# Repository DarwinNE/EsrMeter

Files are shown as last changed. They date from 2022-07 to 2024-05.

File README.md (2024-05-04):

# EsrMeter
An open hardware in-circuit ESR meter for electrolytic capacitors.

This circuit is based on a PIC16F883 that controls a simple lock-in circuit to measure in circuit the ESR and in some cases the capacitance of electrolytic capacitors.

The circuit has been designed by Davide Bucci, the PCB by Etenmenanki using Eagle. The size of the PCBs is compatible with the free version of the program.

A description (in italian language) of the circuit can be found here: https://www.electroyou.it/darwinne/wiki/misurare-esr-di-condensatori-con-circuito-lock-in

Two versions of the PCB exist. The first one has the digital and analog parts split in two. This approach has the advantage that one can test the analog board with something different from the PIC16F883 (i.e. a STM32 or an Arduino board, for instance). The version with the two boards separated requires some corrections, look at the associated files if you try to build them.
The second version has all digital and analog circuits on the same board and it is much more compact. I ordered the PCB on July 24, 2022, I received them and assembled a first prototype at the end of August 2022. It worked at the first attempt, but there is a shift in low ESR values and moderate to large capacitance (>300µF) that I am currently (mid Sept 2022) investigating.

All components are SMD. In the "all in one" boards, two different versions of the PIC16F883 can be used to cope with the pandemic scarcity of components: SOIC and SSOP. I think the PIC16F886 can be used at the place of the PIC16F883 with minimal changes.

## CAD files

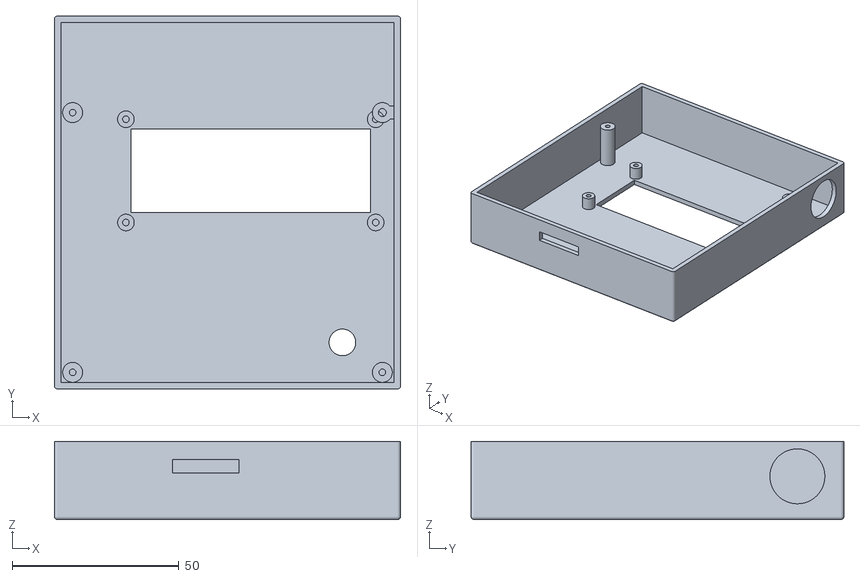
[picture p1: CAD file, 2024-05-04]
3D_printed_box/box.stl
104.0 x 112.0 x 23.5

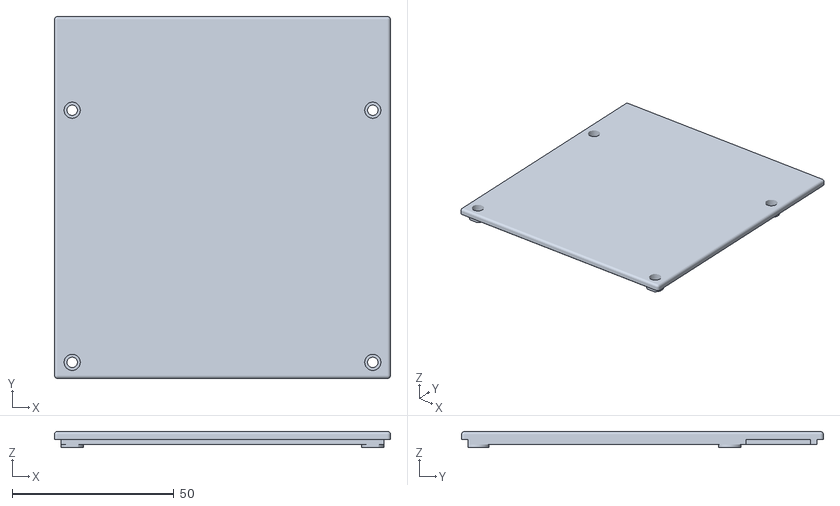
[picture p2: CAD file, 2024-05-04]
3D_printed_box/lid.stl
104.0 x 112.0 x 5.00

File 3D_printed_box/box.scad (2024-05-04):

x_distance_screw=93;
y_distance_screw=78+0;

x_sh=-46.5;
y_sh=-45-6;

x_lcd_pos=-3.5;
y_lcd_pos=-5;

x_lcd_size=72;
y_lcd_size=25;


x_lcd_peg_pos= 2.5; // Position (with respect to the top left aperture of the screen)
y_lcd_peg_pos= 3; // Position (with respect to the top left aperture of the screen)

width_lcd_pegs = 75; // Horizontal distance between screws for the LCD module
height_lcd_pegs= 31; // Vertical distance between screws

x_knob_pos=-12;
y_knob_pos=-69;

x_slot_pos=-55+2;
y_slot_pos=-85;

x_switch_pos=-100+12+8;
y_switch_pos=-69;


x_switch_pos_l=2;
y_switch_pos_l=15;

hole_diam_screw_PCB = 1;
hole_diam_screw_LCD = 1;



internal_height=26;

//top();
translate ([0,0,20]) bottom();

module bottom() { 
    difference() {
        union() {
            difference() {
                union () {
                    difference() {
                        rounded_cube(100+4, 108+4,4);
                        translate([0,0,-2]) cube([110,120,3], center=true);
                    }
                    translate([0,0,-1]) cube([100,108,2], center=true);  
                }
                translate([0,0,-1.5]) cube([98,106,3], center=true);  
            }
            translate([0,0,-3]) {
                translate([x_sh,y_sh,0]) bottom_peg();
                translate([x_sh,y_sh+y_distance_screw,0]) bottom_peg();
                translate([x_sh+x_distance_screw,y_sh,0]) bottom_peg();
                translate([x_sh+x_distance_screw,y_sh+y_distance_screw,0])
                    bottom_peg();
            }
        }
    
        translate([0,0,-2]) {
            translate([x_sh,y_sh,0]) screw_hole();
            translate([x_sh,y_sh+y_distance_screw,0]) screw_hole();
            translate([x_sh+x_distance_screw,y_sh,0]) screw_hole();
            translate([x_sh+x_distance_screw,y_sh+y_distance_screw,0]) screw_hole();
        }
        translate([50,42,-3]) cube([20,20,5], center=true);
        translate([0,-56.5,-4.5]) cube([110,5,8], center=true);
    }
}

module screw_hole()
{
    cylinder(r=2.5,h=6);
}

module bottom_peg()
{
    difference() {
        cylinder(r=3.5,h=4);
        translate([0,0,-2]) cylinder(r=1.6,h=6);
    }
}


module top() {

    difference() {
        union () {
            rounded_cube(100+4, 108+4,internal_height);
        }
        translate([0,0,2]) cube([100,108,internal_height], center=true);    
        translate([0,0,26/2]) cube([100+5,108+5,5], center=true);
        
        // aperture for the LCD, calculated from the left-top screw.
        translate([x_sh+x_distance_screw+x_lcd_pos-x_lcd_size/2,
            y_sh+y_distance_screw+y_lcd_pos-y_lcd_size/2,
            -26/2])
        {    
            cube([x_lcd_size,y_lcd_size,5], center=true);
        }
        
        // Hole for the encoder knob
        translate([x_sh+x_distance_screw+x_knob_pos,
            y_sh+y_distance_screw+y_knob_pos,
            -26/2-2])
        {    
            cylinder(r=4,h=18);
        }
        // Hole for the wires
        translate([x_sh+x_distance_screw+x_slot_pos,
            y_sh+y_distance_screw+y_slot_pos,
            5-2])
        {    
            cube([20,10,4], center=true);
        }
        // Hole for the power switch (top switch)
        /*translate([x_sh+x_distance_screw+x_switch_pos,
            y_sh+y_distance_screw+y_switch_pos,
            -26/2-2])
        {    
            cylinder(r=4,h=18);
        }*/
        
        // Hole for the power switch (lateral switch)
        translate([x_sh+x_distance_screw+x_switch_pos_l,
            y_sh+y_distance_screw+y_switch_pos_l,
            0])
        {    
            rotate([0,90,0]) cylinder(r=16.5/2,h=18);
        }
    }
    // Main PCB and backside screws
    translate([0,0,internal_height-17-internal_height/2+1]) {
        translate([x_sh,y_sh,-17/2]) peg();
        translate([x_sh,y_sh+y_distance_screw,-17/2]) peg();
        translate([x_sh+x_distance_screw,y_sh,-17/2]) peg();
        // This screw is covered by the LCD
        translate([x_sh+x_distance_screw,y_sh+y_distance_screw,-17/2+10])  {
            difference() {
                union() {
                    translate([2,0,3]) {
                        cube([5,4,7],center=true);
                    }
                    cylinder(r=3,h=7);
                }
                translate([0,0,-2]) cylinder(r=1.2,h=10);
            }
        }
    }

    // LCD support screws
    translate([x_sh+x_distance_screw+x_lcd_pos+x_lcd_peg_pos,
            y_sh+y_distance_screw+y_lcd_pos+y_lcd_peg_pos,
            -26/2+2]) {
        small_peg();
        translate([0,-height_lcd_pegs,0]) small_peg();
        translate([-width_lcd_pegs,0,0]) small_peg();
        translate([-width_lcd_pegs,-height_lcd_pegs,0]) small_peg();

    }

}

module peg()
{
    difference() {
        cylinder(r=3,h=17);
        translate([0,0,5]) cylinder(r=hole_diam_screw_PCB,h=13);
    }
}

module small_peg()
{
    difference() {
        cylinder(r=2.5,h=5);
        translate([0,0,0]) cylinder(r=hole_diam_screw_LCD,h=6);
    }
}

/*translate([7,-10,-13.5]) mirror()
        linear_extrude(1)
            #text("Cap tester", size=10, halign = "center", valign="center");  
*/



$fn=64;

module rounded_cube(esizex, esizey,esizez,radius=1)
{
    hull() {
        sizex=esizex-radius*2;
        sizey=esizey-radius*2;
        sizez=esizez-radius*2;
         
        
        translate([sizex/2,sizey/2,sizez/2]) sphere(r=radius);
        translate([-sizex/2,sizey/2,sizez/2]) sphere(r=radius);
        translate([sizex/2,-sizey/2,sizez/2]) sphere(r=radius);
        translate([-sizex/2,-sizey/2,sizez/2]) sphere(r=radius);
        
        translate([sizex/2,sizey/2,-sizez/2]) sphere(r=radius);
        translate([-sizex/2,sizey/2,-sizez/2]) sphere(r=radius);
        translate([sizex/2,-sizey/2,-sizez/2]) sphere(r=radius);
        translate([-sizex/2,-sizey/2,-sizez/2]) sphere(r=radius);
        
    }
}

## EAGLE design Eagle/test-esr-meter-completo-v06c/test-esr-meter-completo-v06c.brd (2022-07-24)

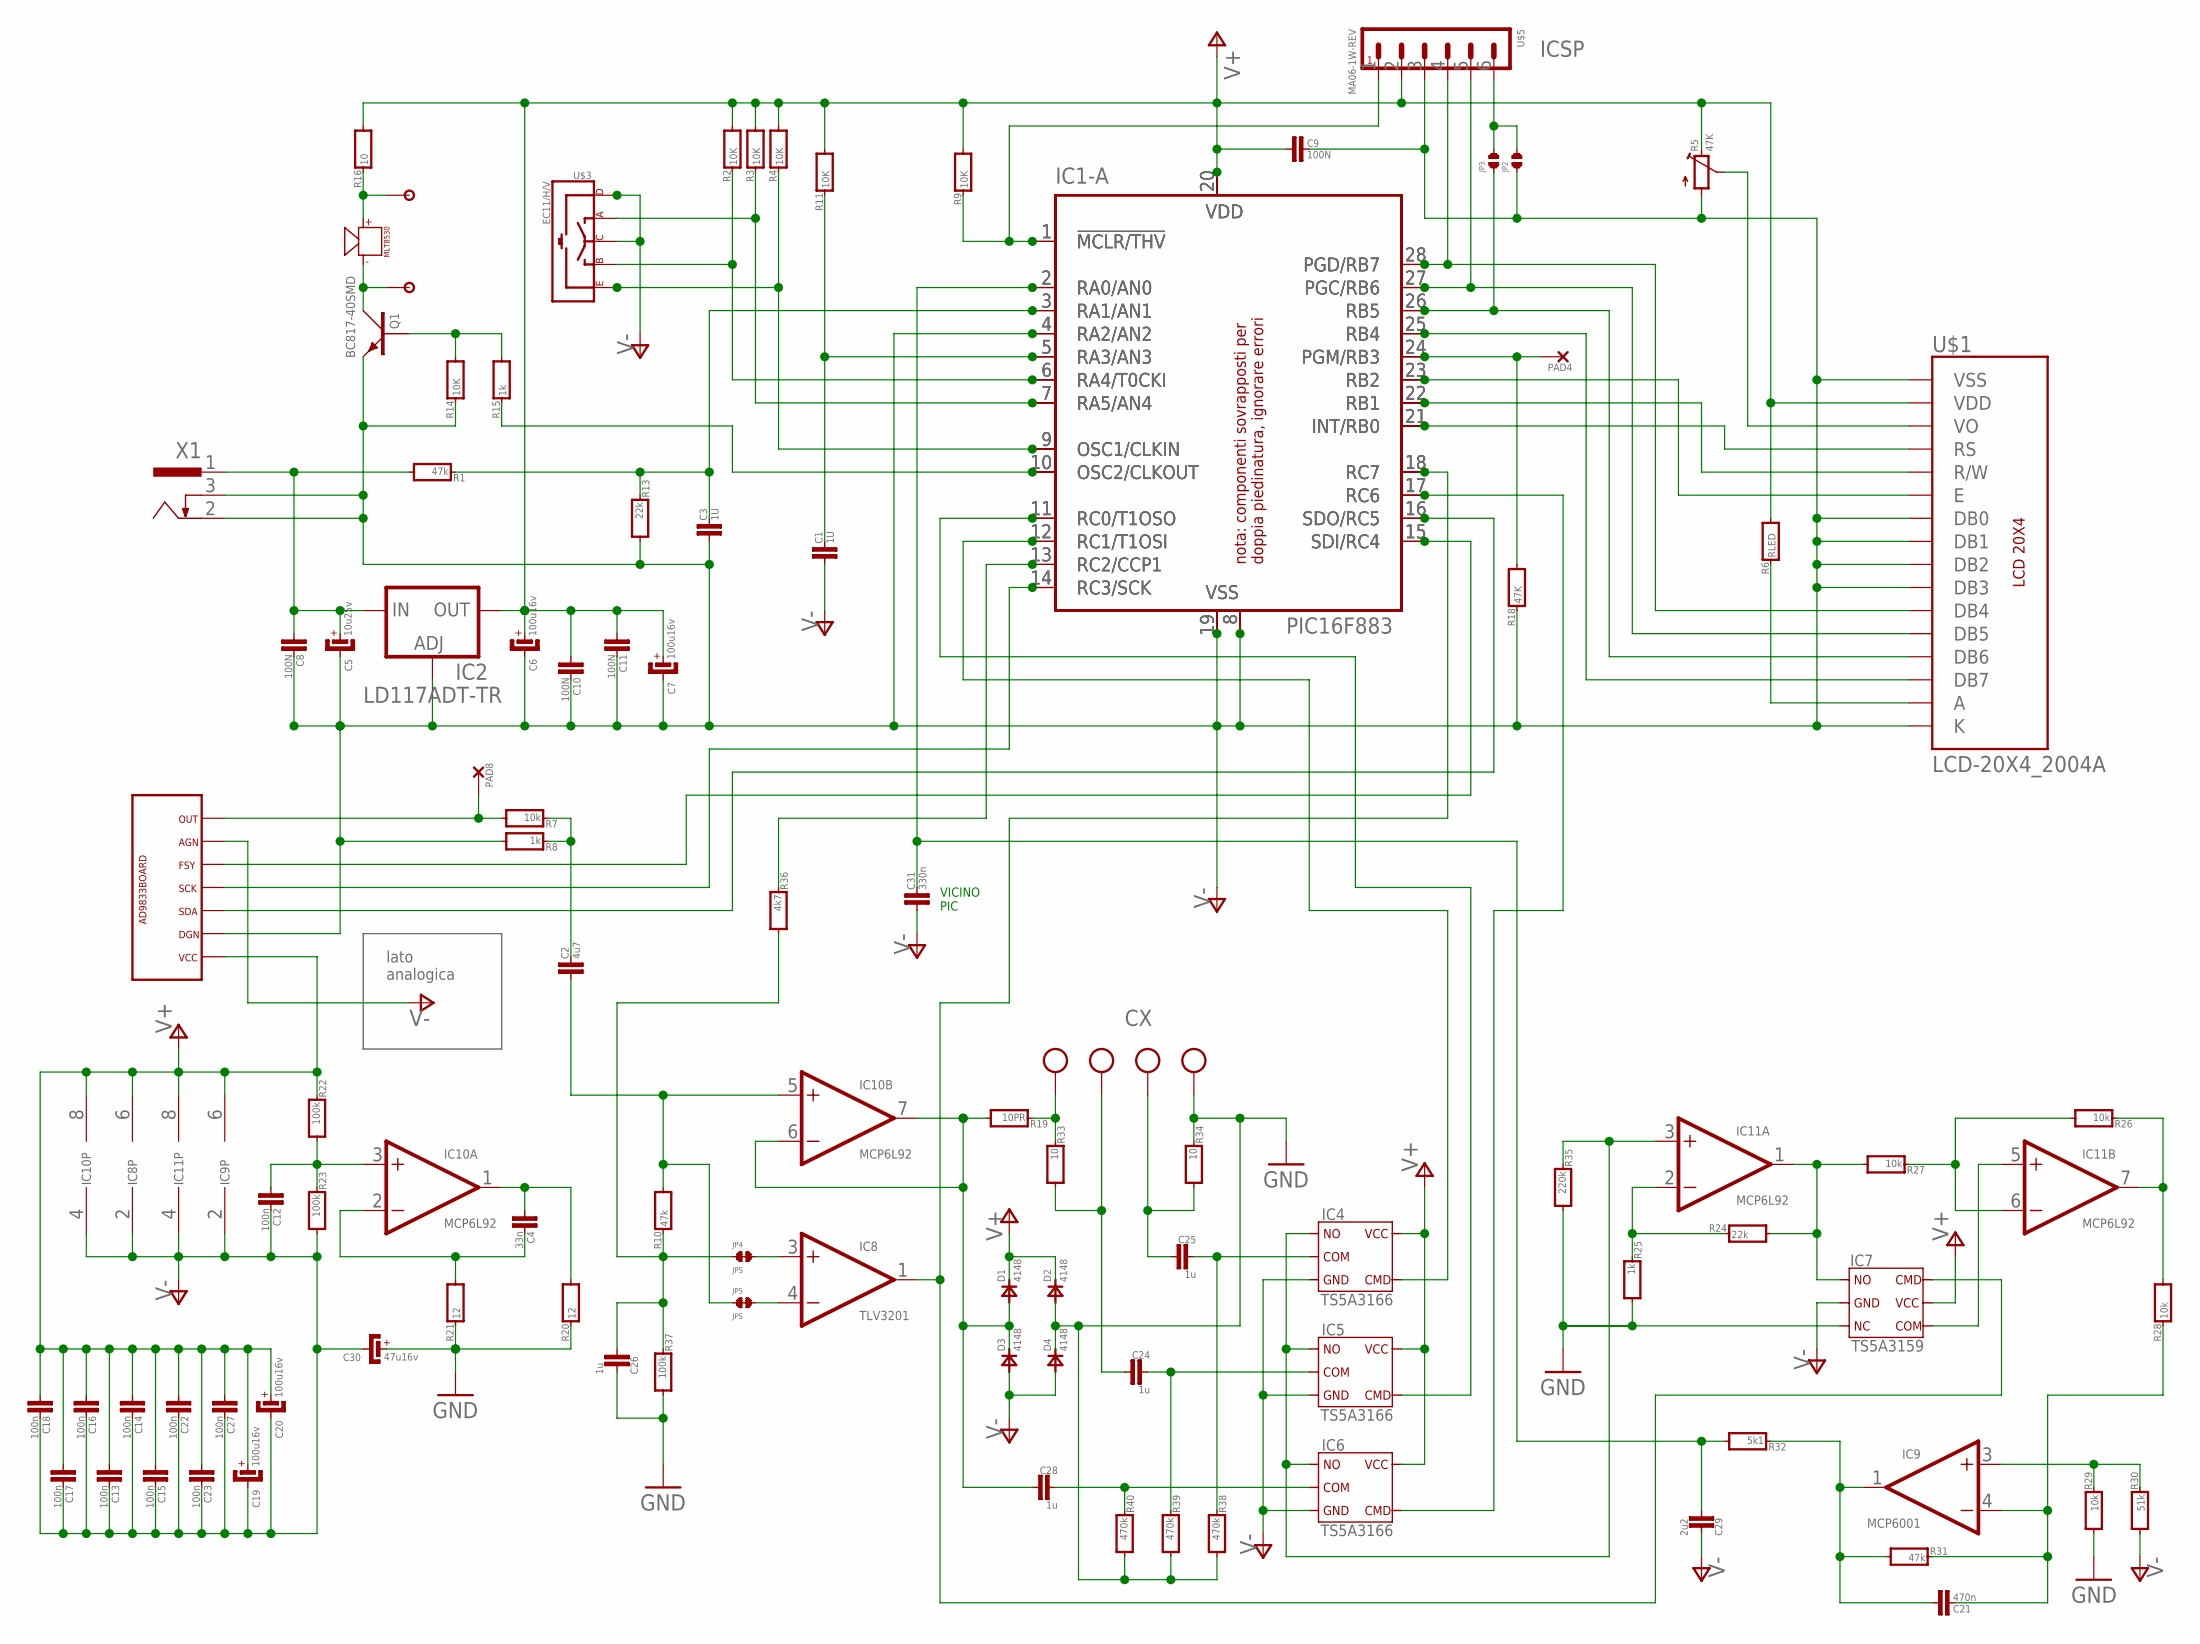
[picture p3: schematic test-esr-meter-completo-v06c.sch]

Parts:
C1, C3: 1U; C0805K
C2: 4u7; C0805K
C4: 33n; C0805K
C5: 10u25v; SMC_D
C6, C7, C19, C20: 100u16v; SMC_D
C8, C9, C10, C11: 100N; C0805K
C12, C13, C14, C15, C16, C17, C18, C22, C23, C27: 100n; C0805K
C21: 470n; C0805K
C24, C25, C26, C28: 1u; C0805K
C29: 2u2; C0805K
C30: 47u16v; SMC_B
C31: 330n; C0805K
D1, D2, D3, D4: 4148; SOD80C
IC1-A: PIC16F883; SO28W
IC2: LD117ADT-TR; DPACK
IC3: PIC16F872SS; SSOP28
IC4, IC5, IC6: TS5A3166; SOT23-5
IC7: TS5A3159; SOT23-6
IC8: TLV3201; SOT23-5
IC9: MCP6001; SOT23-5
IC10, IC11: MCP6L92; SO08
JP2, JP3: JPO
JP4, JP5: JPS
PAD4, PAD8: SMD2; SMD1,27-2,54
Q1: BC817-40SMD; SOT23-BEC
R1, R10, R31: 47k; R0805
R2, R3, R4, R9, R11, R14: 10K; R0805
R5: 47K; RTRIM3339P
R6: RLED; R0805
R7, R26, R27, R28, R29: 10k; R0805
R8, R15, R25: 1k; R0805
R13, R24: 22k; R0805
R16, R33, R34: 10; R0805
R18: 47K; R0805
R19: 10PR; R0805
R20, R21: 12; R0805
R22, R23, R37: 100k; R0805
R30: 51k; R0805
R32: 5k1; R0805
R35: 220k; R0805
R36: 4k7; R0805
R38, R39, R40: 470k; R0805
U$1: LCD-20X4_2004A
U$2: MLT-8530
U$3: EC11/H/V; EC11/V/H
U$4: AD9833BOARD
U$5: MA06-1W-REV
U$6, U$7: PIAZ08
X1: SCD-014A; SCD-014-A
X2: MKDSN1,5/4-5,08

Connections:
GND: C26.2, C30.+, D2.A, D4.C, IC7.3 (NC), R20.1, R21.1, R25.2, R29.2, R34.1, R35.2, R37.2, R38.2, R39.2, R40.2, X2.4
unnamed: IC1-A.10 (OSC2/CLKOUT), IC3.10 (OSC2/CLKOUT), R15.1
unnamed: C26.1, JP4.P$1, R10.1, R36.2, R37.1
unnamed: Q1.B, R14.2, R15.2
unnamed: IC1-A.28 (PGD/RB7), IC3.28 (PGD/RB7), U$1.11 (DB4), U$5.4
unnamed: IC1-A.14 (RC3/SCK), IC3.14 (RC3/SCK), U$4.SCK
unnamed: IC1-A.16 (SDO/RC5), IC3.16 (SDO/RC5), U$4.SDA
unnamed: IC1-A.15 (SDI/RC4), IC3.15 (SDI/RC4), U$4.FSY
unnamed: IC1-A.27 (PGC/RB6), IC3.27 (PGC/RB6), U$1.12 (DB5), U$5.5
unnamed: R5.2 (S), U$1.3 (VO)
unnamed: C2.2, IC10.5 (+IN), JP5.P$1, R10.2
unnamed: IC1-A.25 (RB4), IC3.25 (RB4), U$1.14 (DB7)
unnamed: C29.1, C31.1, IC1-A.2 (RA0/AN0), IC3.2 (RA0/AN0), R32.2
unnamed: C3.1, IC1-A.3 (RA1/AN1), IC3.3 (RA1/AN1), R1.1, R13.1
unnamed: C1.1, IC1-A.5 (RA3/AN3), IC3.5 (RA3/AN3), R11.1
unnamed: IC1-A.23 (RB2), IC3.23 (RB2), U$1.6 (E)
unnamed: IC1-A.22 (RB1), IC3.22 (RB1), U$1.5 (R/W)
unnamed: IC1-A.21 (INT/RB0), IC3.21 (INT/RB0), U$1.4 (RS)
unnamed: IC1-A.6 (RA4/T0CKI), IC3.6 (RA4/T0CKI), R2.1, U$3.B
unnamed: IC1-A.7 (RA5/AN4), IC3.7 (RA5/AN4), R3.1, U$3.A
unnamed: IC1-A.9 (OSC1/CLKIN), IC3.9 (OSC1/CLKIN), R4.1, U$3.E, U$3.E2
unnamed: IC1-A.17 (RC6), IC3.17 (RC6), IC6.4 (CMD)
unnamed: IC1-A.12 (RC1/T1OSI), IC3.12 (RC1/T1OSI), IC4.4 (CMD)
unnamed: IC1-A.11 (RC0/T1OSO), IC3.11 (RC0/T1OSO), IC5.4 (CMD)
unnamed: C24.1, R33.2, X2.2
unnamed: R6.1, U$1.15 (A)
unnamed: IC1-A.24 (PGM/RB3), IC3.24 (PGM/RB3), PAD4.1, R18.2
unnamed: IC1-A.18 (RC7), IC3.18 (RC7), IC7.6 (CMD), IC8.1 (OUT)
unnamed: IC4.1 (NO), IC5.1 (NO), IC6.1 (NO), IC11.3 (+IN), R35.1
unnamed: C5.+, C8.2, IC2.3 (IN), R1.2, X1.1
unnamed: C4.1, IC10.2 (-IN), R21.2
unnamed: R16.1, U$2.+, U$6.P$1
unnamed: IC1-A.1 (!MCLR/THV), IC3.1 (!MCLR/THV), R9.1, U$5.1
unnamed: IC1-A.26 (RB5), IC3.26 (RB5), JP3.P$1, U$1.13 (DB6)
unnamed: JP2.P$2, JP3.P$2, U$5.6
unnamed: Q1.C, U$2.-, U$7.P$1
unnamed: C4.2, IC10.1 (OUT), R20.2
unnamed: IC1-A.13 (RC2/CCP1), IC3.13 (RC2/CCP1), R36.1
unnamed: C12.2, IC10.3 (+IN), R22.2, R23.1
unnamed: IC11.2 (-IN), R24.1, R25.1
unnamed: IC7.1 (NO), IC11.1 (OUT), R24.2, R27.2
unnamed: IC11.7 (OUT), R26.1, R28.2
unnamed: IC11.6 (-IN), R26.2, R27.1
unnamed: IC7.4 (COM), IC11.5 (+IN)
unnamed: IC9.3 (+IN), R29.1, R30.1
unnamed: C21.1, IC9.4 (-IN), R28.1, R31.1
unnamed: C2.1, R7.1, R8.1
unnamed: PAD8.1, R7.2, U$4.OUT
unnamed: R19.1, R33.1, X2.1
unnamed: C25.1, R34.2, X2.3
unnamed: C28.1, D1.A, D3.C, IC10.6 (-IN), IC10.7 (OUT), R19.2
unnamed: C24.2, IC5.2 (COM), R39.1
unnamed: C25.2, IC4.2 (COM), R38.1
unnamed: C28.2, IC6.2 (COM), R40.1
unnamed: IC8.4 (-IN), JP5.P$2
unnamed: IC8.3 (+IN), JP4.P$2
unnamed: C21.2, IC9.1 (OUT), R31.2, R32.1
V+: C6.+, C7.+, C9.2, C10.2, C11.2, C13.2, C14.2, C15.2, C16.2, C17.2, C18.2, C19.+, C20.+, C22.2, C23.2, C27.2, D1.C, D2.C, IC1-A.20 (VDD), IC2.4 (OUT), IC3.20 (VDD), IC4.6 (V+), IC5.6 (V+), IC6.6 (V+), IC7.5 (V+), IC8.6 (V+), IC9.6 (V+), IC10.8 (V+), IC11.8 (V+), R2.2, R3.2, R4.2, R5.3 (E), R6.2, R9.2, R11.2, R16.2, R22.1, U$1.2 (VDD), U$4.VCC, U$5.2
V-: C1.2, C3.2, C5.-, C6.-, C7.-, C8.1, C9.1, C10.1, C11.1, C12.1, C13.1, C14.1, C15.1, C16.1, C17.1, C18.1, C19.-, C20.-, C22.1, C23.1, C27.1, C29.2, C30.-, C31.2, D3.A, D4.A, IC1-A.4 (RA2/AN2), IC1-A.8 (VSS), IC1-A.19 (VSS), IC2.1 (ADJ), IC3.4 (RA2/AN2), IC3.8 (VSS), IC3.19 (VSS), IC4.3 (GND), IC5.3 (GND), IC6.3 (GND), IC7.2 (GND), IC8.2 (V-), IC9.2 (V-), IC10.4 (V-), IC11.4 (V-), JP2.P$1, Q1.E, R5.1 (A), R8.2, R13.2, R14.1, R18.1, R23.2, R30.2, U$1.1 (VSS), U$1.7 (DB0), U$1.8 (DB1), U$1.9 (DB2), U$1.10 (DB3), U$1.16 (K), U$3.C, U$3.D, U$3.D2, U$4.AGN, U$4.DGN, U$5.3, X1.2, X1.3

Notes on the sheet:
ICSP
nota: componenti sovrapposti per doppia piedinatura, ignorare errori
VICINO PIC
lato analogica

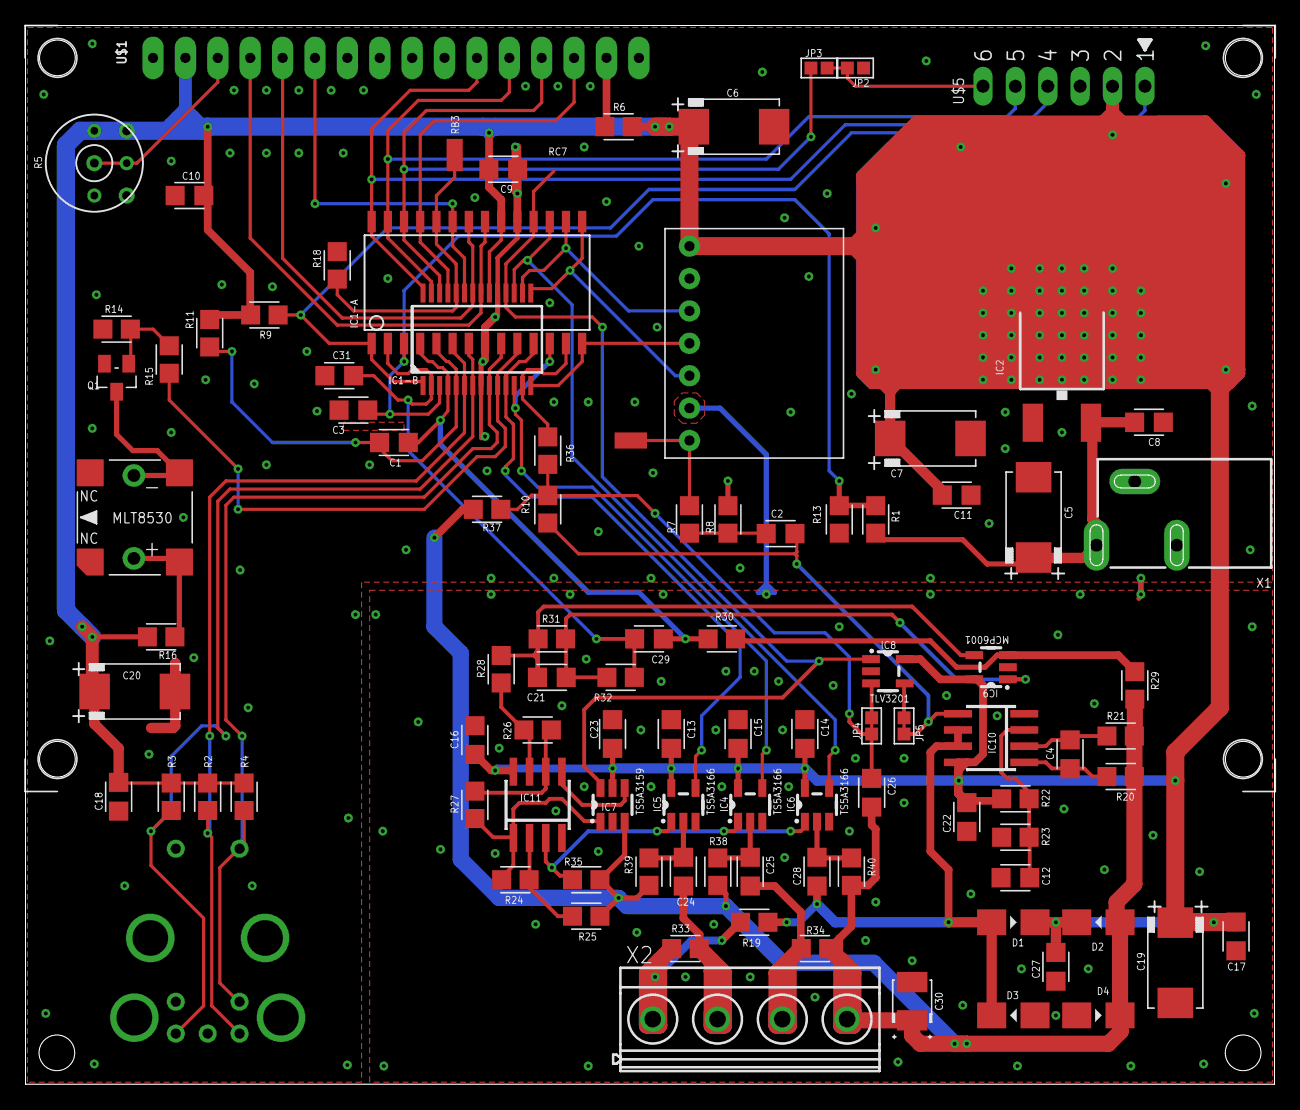
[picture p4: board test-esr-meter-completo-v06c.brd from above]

Board: 2 copper layers, 97.9 x 83.0 mm, 100 parts (0 on the bottom side), 59 nets.

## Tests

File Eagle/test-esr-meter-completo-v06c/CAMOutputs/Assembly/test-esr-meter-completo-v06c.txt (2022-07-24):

Partlist exported from /Users/davidebucci/Desktop/test-esr-meter-completo-v06c/test-esr-meter-completo-v06c.sch at 24/07/2022 22:13

Qty Value           Device          Package         Parts                                            Description                                                   MF        MPN             OC_FARNELL OC_NEWARK
1                   SCD-014A        SCD-014-A       X1                                               Power Jack 2.5mm                                                                        unknown    unknown  
2                   SMD2            SMD1,27-2,54    PAD4, PAD8                                       SMD PAD                                                                                                     
3   10              R-EU_R0805      R0805           R16, R33, R34                                    RESISTOR, European symbol                                                                                   
4   100N            C-EUC0805K      C0805K          C8, C9, C10, C11                                 CAPACITOR, European symbol                                                                                  
3   100k            R-EU_R0805      R0805           R22, R23, R37                                    RESISTOR, European symbol                                                                                   
10  100n            C-EUC0805K      C0805K          C12, C13, C14, C15, C16, C17, C18, C22, C23, C27 CAPACITOR, European symbol                                                                                  
4   100u16v         CPOL-EUSMCD     SMC_D           C6, C7, C19, C20                                 POLARIZED CAPACITOR, European symbol                                                                        
6   10K             R-EU_R0805      R0805           R2, R3, R4, R9, R11, R14                         RESISTOR, European symbol                                                                                   
1   10PR            R-EU_R0805      R0805           R19                                              RESISTOR, European symbol                                                                                   
5   10k             R-EU_R0805      R0805           R7, R26, R27, R28, R29                           RESISTOR, European symbol                                                                                   
1   10u25v          CPOL-EUSMCD     SMC_D           C5                                               POLARIZED CAPACITOR, European symbol                                                                        
2   12              R-EU_R0805      R0805           R20, R21                                         RESISTOR, European symbol                                                                                   
2   1U              C-EUC0805K      C0805K          C1, C3                                           CAPACITOR, European symbol                                                                                  
3   1k              R-EU_R0805      R0805           R8, R15, R25                                     RESISTOR, European symbol                                                                                   
4   1u              C-EUC0805K      C0805K          C24, C25, C26, C28                               CAPACITOR, European symbol                                                                                  
1   220k            R-EU_R0805      R0805           R35                                              RESISTOR, European symbol                                                                                   
2   22k             R-EU_R0805      R0805           R13, R24                                         RESISTOR, European symbol                                                                                   
1   2u2             C-EUC0805K      C0805K          C29                                              CAPACITOR, European symbol                                                                                  
1   330n            C-EUC0805K      C0805K          C31                                              CAPACITOR, European symbol                                                                                  
1   33n             C-EUC0805K      C0805K          C4                                               CAPACITOR, European symbol                                                                                  
4   4148            4148            SOD80C          D1, D2, D3, D4                                                                                                                                               
3   470k            R-EU_R0805      R0805           R38, R39, R40                                    RESISTOR, European symbol                                                                                   
1   470n            C-EUC0805K      C0805K          C21                                              CAPACITOR, European symbol                                                                                  
1   47K             R-EU_R0805      R0805           R18                                              RESISTOR, European symbol                                                                                   
1   47K             R-TRIMM3339P    RTRIM3339P      R5                                               Trimm resistor                                                                                              
3   47k             R-EU_R0805      R0805           R1, R10, R31                                     RESISTOR, European symbol                                                                                   
1   47u16v          CPOL-EUSMCB     SMC_B           C30                                              POLARIZED CAPACITOR, European symbol                                                                        
1   4k7             R-EU_R0805      R0805           R36                                              RESISTOR, European symbol                                                                                   
1   4u7             C-EUC0805K      C0805K          C2                                               CAPACITOR, European symbol                                                                                  
1   51k             R-EU_R0805      R0805           R30                                              RESISTOR, European symbol                                                                                   
1   5k1             R-EU_R0805      R0805           R32                                              RESISTOR, European symbol                                                                                   
1   AD9833BOARD     AD9833BOARD     AD9833BOARD     U$4                                                                                                                                                          
1   BC817-40SMD     BC817-40SMD     SOT23-BEC       Q1                                               NPN Transistor                                                                                              
1   EC11/H/V        EC11/H/V        EC11/V/H        U$3                                                                                                                                                          
2   JPO             JPO             JPO             JP2, JP3                                                                                                                                                     
2   JPS             JPS             JPS             JP4, JP5                                                                                                                                                     
1   LCD-20X4_2004A  LCD-20X4_2004A  LCD-20X4_2004A  U$1                                                                                                                                                          
1   LD117ADT-TR     LD117ADT-TR     DPACK           IC2                                              Low drop fixed and adjustable positive voltage regulators 1 A                                               
1   MA06-1W-REV     MA06-1W-REV     MA06-1W-REV     U$5                                                                                                                                                          
1   MCP6001         MCP6001         SOT23-5         IC9                                                                                                                                                          
2   MCP6L92         MCP6L92         SO08            IC10, IC11                                                                                                                                                   
1   MKDSN1,5/4-5,08 MKDSN1,5/4-5,08 MKDSN1,5/4-5,08 X2                                               MKDSN 1,5/ 4-5,08 Printklemme                                                                               
1   MLT-8530        MLT-8530        MLT-8530        U$2                                                                                                                                                          
2   PIAZ08          PIAZ08          PIAZ08          U$6, U$7                                                                                                                                                     
1   PIC16F872SS     PIC16F872SS     SSOP28          IC3                                              MICROCONTROLLER                                               MICROCHIP PIC16F872-I/SS  1084299    96K3887  
1   PIC16F883       PIC16F876SO     SO28W           IC1-A                                            MICROCONTROLLER                                               MICROCHIP PIC16F876-20/SO 9761268    12C1950  
1   RLED            R-EU_R0805      R0805           R6                                               RESISTOR, European symbol                                                                                   
1   TLV3201         TLV3201         SOT23-5         IC8                                                                                                                                                          
1   TS5A3159        TS5A3159        SOT23-6         IC7                                                                                                                                                          
3   TS5A3166        TS5A3166        SOT23-5         IC4, IC5, IC6

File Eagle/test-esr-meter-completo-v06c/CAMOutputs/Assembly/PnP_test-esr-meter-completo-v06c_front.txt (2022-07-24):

C1	28.89	50.32	0.00	1U	C0805K
C10	12.86	69.69	0.00	100N	C0805K
C11	73.03	46.20	180.00	100N	C0805K
C12	77.63	16.19	0.00	100n	C0805K
C13	50.64	27.46	270.00	100n	C0805K
C14	61.12	27.46	270.00	100n	C0805K
C15	55.88	27.46	270.00	100n	C0805K
C16	35.24	26.99	270.00	100n	C0805K
C17	94.93	11.59	90.00	100n	C0805K
C18	7.30	22.54	90.00	100n	C0805K
C19	90.17	9.53	270.00	100u16v	SMC_D
C2	59.21	43.18	0.00	4u7	C0805K
C20	8.57	30.80	0.00	100u16v	SMC_D
C21	41.27	31.91	0.00	470n	C0805K
C22	73.82	20.96	90.00	100n	C0805K
C23	46.04	27.46	270.00	100n	C0805K
C24	51.59	16.67	90.00	1u	C0805K
C25	56.83	16.67	90.00	1u	C0805K
C26	66.36	22.86	270.00	1u	C0805K
C27	80.80	9.21	90.00	100n	C0805K
C28	62.07	16.67	90.00	1u	C0805K
C29	48.90	34.93	0.00	2u2	C0805K
C3	25.72	52.86	180.00	1U	C0805K
C30	69.53	6.51	90.00	47u16v	SMC_B
C31	24.61	55.56	180.00	330n	C0805K
C4	81.92	25.88	270.00	33n	C0805K
C5	79.06	44.45	90.00	10u25v	SMC_D
C6	55.56	75.09	0.00	100u16v	SMC_D
C7	70.96	50.64	0.00	100u16v	SMC_D
C8	88.11	51.91	180.00	100N	C0805K
C9	37.47	71.76	180.00	100N	C0805K
D1	77.47	12.70	180.00	4148	SOD80C
D2	84.14	12.70	0.00	4148	SOD80C
D3	77.47	5.40	0.00	4148	SOD80C
D4	84.14	5.40	180.00	4148	SOD80C
IC1-A	35.40	62.87	0.00	PIC16F883	SO28W
IC10	75.72	27.15	90.00	MCP6L92	SO08
IC11	40.16	21.91	0.00	MCP6L92	SO08
IC2	81.28	55.46	0.00	LD117ADT-TR	DPACK
IC3	35.40	58.42	0.00	PIC16F872SS	SSOP28
IC4	56.83	21.91	90.00	TS5A3166	SOT23-5
IC5	51.59	21.91	90.00	TS5A3166	SOT23-5
IC6	62.07	21.91	90.00	TS5A3166	SOT23-5
IC7	46.04	21.91	90.00	TS5A3159	SOT23-6
IC8	67.63	32.38	0.00	TLV3201	SOT23-5
IC9	75.72	32.70	180.00	MCP6001	SOT23-5
JP2	65.09	79.69	180.00	JPO	JPO
JP3	62.23	79.69	0.00	JPO	JPO
JP4	66.36	28.10	90.00	JPS	JPS
JP5	68.90	28.10	90.00	JPS	JPS
PAD4	33.66	72.87	0.00		SMD1,27-2,54
PAD8	47.47	50.48	90.00		SMD1,27-2,54
Q1	7.14	55.40	180.00	BC817-40SMD	SOT23-BEC
R1	66.67	44.29	270.00	47k	R0805
R10	40.96	45.09	270.00	47k	R0805
R11	14.45	58.90	90.00	10K	R0805
R13	63.82	44.29	270.00	22k	R0805
R14	7.14	59.21	0.00	10K	R0805
R15	11.27	56.83	90.00	1k	R0805
R16	10.64	35.08	180.00	10	R0805
R18	24.45	64.21	270.00	47K	R0805
R19	57.15	12.70	0.00	10PR	R0805
R2	14.29	22.54	90.00	10K	R0805
R20	85.88	24.13	180.00	12	R0805
R21	85.88	27.30	180.00	12	R0805
R22	77.63	22.38	0.00	100k	R0805
R23	77.63	19.37	180.00	100k	R0805
R24	38.42	16.03	180.00	22k	R0805
R25	43.97	13.18	0.00	1k	R0805
R26	40.16	27.78	0.00	10k	R0805
R27	35.24	21.91	270.00	10k	R0805
R28	37.31	32.54	270.00	10k	R0805
R29	87.00	31.27	270.00	10k	R0805
R3	11.43	22.54	90.00	10K	R0805
R30	54.61	34.93	180.00	51k	R0805
R31	41.27	34.93	0.00	47k	R0805
R32	46.67	31.91	0.00	5k1	R0805
R33	51.75	10.64	0.00	10	R0805
R34	61.91	10.64	180.00	10	R0805
R35	43.97	16.03	0.00	220k	R0805
R36	40.96	49.69	270.00	4k7	R0805
R37	36.20	45.09	180.00	100k	R0805
R38	54.29	16.67	270.00	470k	R0805
R39	48.90	16.67	270.00	470k	R0805
R4	17.14	22.54	90.00	10K	R0805
R40	64.77	16.67	270.00	470k	R0805
R6	46.51	75.09	0.00	RLED	R0805
R7	52.07	44.29	90.00	10k	R0805
R8	55.09	44.29	90.00	1k	R0805
R9	18.73	60.33	180.00	10K	R0805
U$2	12.13	44.39	180.00	MLT-8530	MLT-8530

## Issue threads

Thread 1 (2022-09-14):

Could you provide a compiled PIC16F883 HEX file?

lpkf2018, 2022-09-14:
Hello, I am very interested in your ESR meter and I am planning to make one myself, I lack the necessary compilation environment and software here, can you post a compiled PIC16F883 HEX file? Thank you very much!

DarwinNE, 2022-09-14:
Hello,
   I added the .hex and .lst files.
Please be warned that this is an onging project. If you assemble it consider that not everything is perfectly finalized.

I'm currently working on the single board version of the circuit. I assembled it a few days ago and it kind of works. However, there is a shift that appears for low resistances and moderate and large capacitance (i.e. >300µF) and I haven't yet understood from where it comes.

BTW I can send you a board if you want to try to assemble the circuit. I have five of them and I am not planning to assemble more than one or two prototypes.

lpkf2018, 2022-10-28:
Hello, sir.

 Did you solve the problem you mentioned last time? I saw you tweeted that you got a capacitor wrong, is it working perfectly now? If so, please let me know, I'm assembling this ESR METER. I'll give you a very good feedback when it's done. I have BLUE2 ESR METER, MESR-100, mR71 and I will let you know the comparison results.

DarwinNE, 2022-10-30:
Hi,
   yes, I found a capacitor that had the wrong value in my prototype.

After replacing it, the circuit works much better. It is still slightly off (about 5-10%) in the ESR reading with respect to the other prototypes. I have not worked on this lately, but I may investigate a day or another. I have used this version of the circuit a little and I found it useful. If you build yours, let me know how it performs.

BTW, it may be interesting to look at this article I co-wrote. It is in Italian, but you may use some automatic translation: https://www.electroyou.it/darwinne/wiki/misurare-esr-di-condensatori-con-circuito-lock-in

Cheers,
D.

DarwinNE, 2022-11-10:
To have an idea, here is a picture I took of the circuit. I measured (one year ago) the pictured resistance in DC with a much higher current and I obtained 0.328 Ω. That gives an error of less than 5% that seems acceptable.

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

dangermousehouse, 2023-07-28:
Nearly done, just need to source IC10, IC11.

Have I fitted the AD9833 board correctly?
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

The revised project board with holes for the 4 line display (LCD-20X4_2004A) fits perfectly
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

DarwinNE, 2023-07-28:
Hello,
   very nice! On mine, the AD9833 is mounted the same way:

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

I have a 4-line display, too, I'd like to add some information such the frequency used for the measurement of the capacitance and the ESR in the automatic mode.

BTW, mounting the PIC required some care for the soldering, a good magnifier lens was particularly useful for the task!

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

DarwinNE, 2023-07-28:
Hello,
   very nice! On mine, the AD9833 is mounted the same way:

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

I have a 4-line display, too, I'd like to add some information such the frequency used for the measurement of the capacitance and the ESR in the automatic mode.

BTW, mounting the PIC required some care for the soldering, a good magnifier lens was particularly useful for the task!

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

DarwinNE, 2024-05-23:
@dangermousehouse I would be interested to have a feedback about the circuit you built. Are you satisfied of the performances? Is there a room for improvement somewhere, in your opinion?
Kind regards,
D.

dangermousehouse, 2024-05-29:
Hi Davide;

Thanks for following up, I've made the board but never programmed the PIC

I'll finish the project and then be able to give you some useful feedback

Matt House
***@***.***
+64275737837
________________________________
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

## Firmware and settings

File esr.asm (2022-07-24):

; *****************************************************************************
;               esr.asm
;       A simple ESR measuring system exploiting lock-in techniques
;       Davide Bucci, 2021
;       Version 1.1
; *****************************************************************************

; License:
; --------

;    Copyright (C) 2021-2022 Davide Bucci  davbucciPleaseNoSpamHerE@tiscali.it

;    This program is free software; you can redistribute it and/or modify
;    it under the terms of the GNU General Public License as published by
;    the Free Software Foundation; either version 3 of the License, or
;    (at your option) any later version.

;    This program is distributed in the hope that it will be useful,
;    but WITHOUT ANY WARRANTY; without even the implied warranty of
;    MERCHANTABILITY or FITNESS FOR A PARTICULAR PURPOSE.  See the
;    GNU General Public License for more details.

;    You should have received a copy of the GNU General Public License
;    along with this program; if not, write to the Free Software
;    Foundation, Inc., 675 Mass Ave, Cambridge, MA 02139, USA.

        ERRORLEVEL -302         ; disable the annoying warning
                                ; "Register in operand not in bank 0.
                                ; Ensure bank bits are correct."

#include <p16F883.inc>
   __config (_INTRC_OSC_NOCLKOUT & _WDT_OFF & _PWRTE_ON & _BOREN_ON & _MCLRE_ON & _CP_OFF & _IESO_OFF & _FCMEN_OFF & _DEBUG_OFF)

; Constants
OSC_LOTHRESHOLD equ     .35     ; Error if the ampl. A_VH is lower than this.
OSC_HITHRESHOLD equ     .240    ; Error if the ampl. A_VH is higher than this.
CURR_THRESHOLD  equ     .2      ; Threshold for high byte of A-B (current)

; Control lines of the display device
; Control port used for LCD display

DATALCD         equ     PORTB
TRISLCD         equ     TRISB

E               equ     2
RS              equ     0
RW              equ     1

DATA4           equ     7
DATA5           equ     6
DATA6           equ     5
DATA7           equ     4

PORTFSYNC       equ     PORTC
TRISFSYNC       equ     TRISC
FSYNC           equ     RC4
VSYNC           equ     RC7

; These registers must be in the same page of the DATALCD register
TMP             equ     0x20        ; Dummy for LCD nibble mode
CNT             equ     0x21        ; Counter
SDR             equ     0x22        ; Short Delay Register
LDR             equ     0x23        ; Long Delay Register
TMP1            equ     0x24        ; Dummy for reversing bit order
UNIT            equ     0x25        ; Multiplier for measuring unit for caps.
ESRM            equ     0x26        ; Flag: measure ESR or not.
MEASUREESR      equ     0x00        ; Constants for ESRM
NOESR           equ     0x01
WRITEF          equ     0x27        ; Write the frequency when calling SetFreq
ACTIVE          equ     0x01
NOACTIVE        equ     0x00

MEAS_OK         equ     0x00
ERR_OSCLO       equ     0x01
ERR_OSCHI       equ     0x02
ERR_LOWCURR     equ     0x03

CURW            equ     0x28        ; Used in the automatic measurement of C.
OLDW            equ     0x29        ; Same as before.
TMP_1           equ     0x2A
HND             equ     0x2B
DEC             equ     0x2C
UNT             equ     0x2D

; Used to send 16 bit data via SPI, combined with the w register.
SENDL           equ     0x2E
SHOWNC          equ     0x2F            ; Different from zero if a C is shown

; Used for the div_32_16 operator: the two operands, the result and the
; remainder
divid0          equ     0x30            ; Most significant byte
divid1          equ     0x31
divid2          equ     0x32
divid3          equ     0x33            ; Least significant byte
divisH          equ     0x34
divisL          equ     0x35
remdrH          equ     0x36
remdrL          equ     0x37
ESRW            equ     0x38
LOOPCOUNT       equ     0x39
ALTESRLL        equ     0x3A            ; Alternate measurement of ESR
ALTESRLH        equ     0x3B            ; used to understand if the DUT
ALTESRHL        equ     0x3C            ; is a resistance.
ALTESRHH        equ     0x3D

SOUNDOFF        equ     0x3E            ; =0 sound on =1 sound off

; aHH:aHL:aLH:aLL*bH:bL -> a6:a5:aHH:aHL:aLH:aLL

aLL             equ     0x40
aLH             equ     0x41
aHL             equ     0x42
aHH             equ     0x43
a5              equ     0x44
a6              equ     0x45

bL              equ     0x46
bH              equ     0x47

c1              equ     0x48
c2              equ     0x49
c3              equ     0x4A
c4              equ     0x4B

bitcnt          equ     0x4C

USR             equ     0x4D
MENUSTATE       equ     0x4E


bcd             equ     0x50
; memory used up to bcd+4 included
cnt             equ     0x55
ii              equ     0x56
bin             equ     0x57
; memory used up to bin+3 included

; Error constants for the CalcCap routine
FREQLO          equ     0x01
FREQHI          equ     0x02
CAP_OK          equ     0x00

CAPHH           equ     0x5B    ; The current value of the capacity.
CAPHL           equ     0x5C
CAPLH           equ     0x5D
CAPLL           equ     0x5E

FLAG            equ     0x5F

indf            equ     0
fsr             equ     4

NOZ             equ     0x60


DIVH            equ     0x65
DIVL            equ     0x6F

REGBLL          equ     0x66
REGBLH          equ     0x67
REGBHL          equ     0x68
REGBHH          equ     0x69
REGCLL          equ     0x6A
REGCLH          equ     0x6B
REGCHL          equ     0x6C
REGCHH          equ     0x6D
MCOUNT          equ     0x6E

; Configuration for the measurement control
CTRLP           equ     PORTC
TRISCTRL        equ     TRISC
PWMPIN          equ     RC2

; The value of the ESR is calculated as
; 10*(V_B-V_C)/(V_A-V_B)
CTRLA           equ     RC6
CTRLB           equ     RC0
CTRLC           equ     RC1

A_VH            equ     0x70
A_VL            equ     0x71

B_VH            equ     0x72
B_VL            equ     0x73

C_VH            equ     0x74
C_VL            equ     0x75

; The result of each ADC conversion (temporary)
STOREH          equ     0x76
STOREL          equ     0x77

; The two 14-bit words that define the frequency on the AD9833
MSBH            equ     0x78
MSBL            equ     0x79
LSBH            equ     0x7A
LSBL            equ     0x7B

; The index in the frequency table
FREQ            equ     0x7C
FMAX            equ     .11     ; FREQ can range from 0 to FMAX (both included)

; The index in the DC value
DCVAL           equ     0x7D

; User interface (CHVAL!=0 means that the knob has moved)
BSENSE          equ     0x7E
CHVAL           equ     0x7F
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

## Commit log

2021-05-02 Added PCBs done with Eagle by Etemenanki of the Electroyou.it forum.
    [test-esr-meter-analog-v0.9a.brd, test-esr-meter-analog-v0.9a.sch, test-esr-meter-pic-v0.4.brd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]
2021-06-02 Update some details and component values.
    [test-esr-meter-analog-v0.9a.brd, test-esr-meter-analog-v0.9a.sch]
2021-06-27 Version with PIC16F883 on the PCB.
2021-07-05 Check for low test current situations.
2021-07-12 Automatic measurement of capacitance and ESR. Still much to improve.
2021-07-18 Measure the battery voltage when switched on.
2021-07-23 Correct the number of ADC acquisitions.
    [esr.asm]
2021-12-14 Removed the obsolete version for the prototype with the PIC16F690.
2021-12-19 Improved version, with better frequency ranging for the capacitance measurements. Still somewhat slow and some cluncky messages are shown on the display during the measurements.
2021-12-19 Cleaner messages when measuring the capacitance.
2021-12-19 Faster measurement of the capacitance.
2021-12-22 Better frequency selection algorithm to measure capacitance. Faster measurements.
2021-12-23 Better synchronization with oscillator during measurements.
    [esr.asm]
2022-01-24 Introducing calibration coefficients so to have precise measurements down to 10 nF.
2022-02-10 Tweaked a few coefficients, corrected bugs and implemented an algorithm to recognize resistances in automatic mode.
    [esr.asm]
2022-03-09 Add minimum voltage test 6.7V for the battery.
2022-03-20 Corrected a bug that prevented beep length to be related to ESR.
    [esr.asm]
2022-07-07 Improve speed to read large capacitors.
2022-07-07 Renamed directories containing the schematics and PCB's
    [test-esr-meter-pic-v0.4.brd, test-esr-meter-pic-v0.4.sch]
2022-07-07 Added README files with corrections for the analog and digital boards.
2022-07-24 Add a single board version made by Etenmenanki of the ElectroYou forum.
    [copper_bottom.gbr, copper_top.gbr, drill_1_16.xln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]
2024-05-04 Add a 3D-printed box, designed with OpenSCAD.
    [box.scad, box.stl, lid.stl]
